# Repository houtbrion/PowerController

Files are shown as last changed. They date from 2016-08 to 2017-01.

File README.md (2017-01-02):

# PowerController
常時運転するRaspberry Piの動作と周囲の環境をArduinoで監視し，
ArduinoでRaspberry Piに供給する電源を制御するシステム．

Raspberry Piが不調に陥った場合に，遠隔からRaspberry Piの電源を強制的にON/OFF
するためにArduinoを遠隔から制御するためのI/Fも提供する．

# 1. システム構成
システムは電源を制御される側のRaspberry Piと，Raspberry Pi用の電源を
制御するArduino，電源制御用端末であるArduinoに遠隔から手動でコマンドを
投入するための遠隔ログイン端末の3種類で構成される．

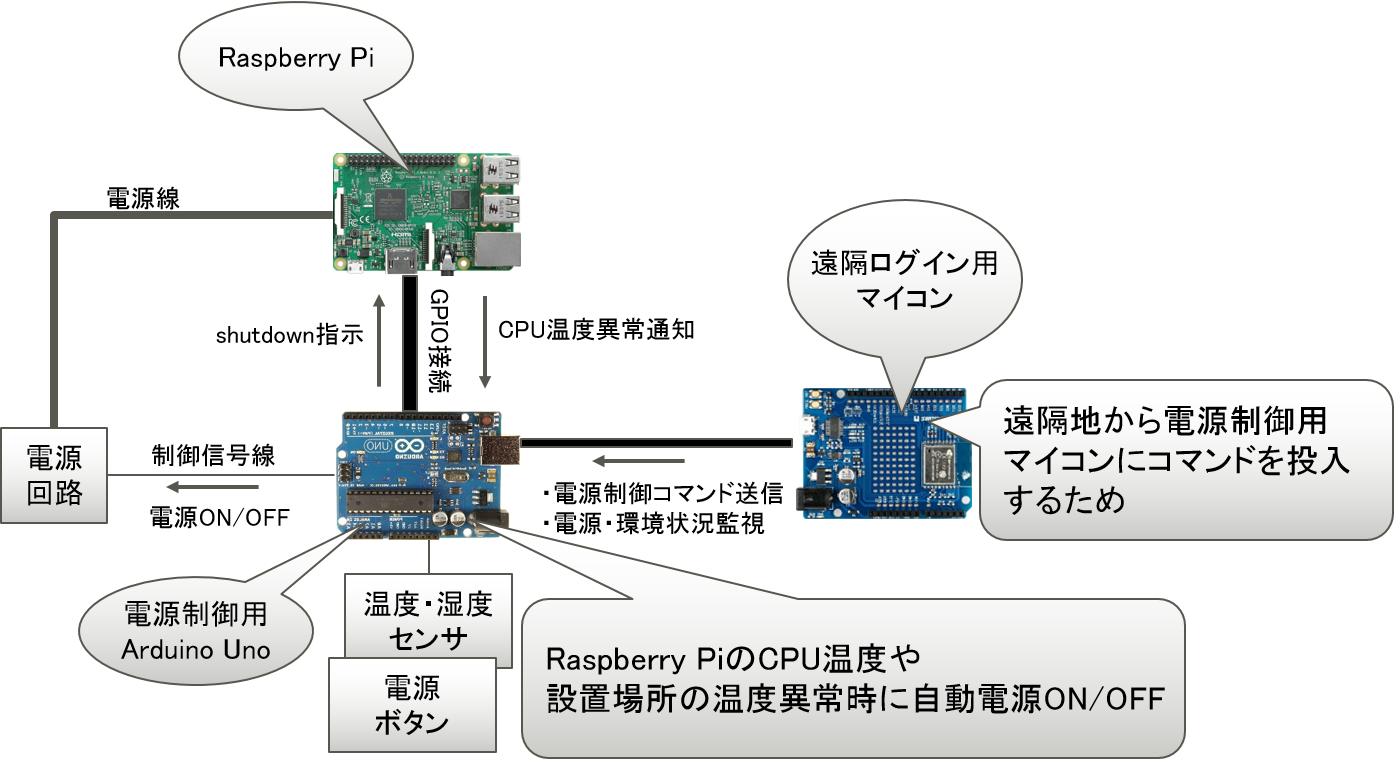
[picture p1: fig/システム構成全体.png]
システム構成図


## 1.1 Raspberry PiとArduinoの連携
電源を制御される側のRaspberry PiのGPIOと電源を制御する側のArduinoのデジタル端子を
接続し，信号をやり取りすることで，人によるRaspberry Piの運用環境の監視やRaspbery Piの
動作の監視を自動化する．

* 強制shutdown信号
Raspberry PiのGPIO端子でArduinoの特定の端子の電圧をdaemonで監視し，Arduinoのある端子の
電圧がHIGHになった場合に，なにかの異常と判定し，shutdownを行う．

* keep alive信号
Raspberry PiのGPIOの特定のピンを定期的にHIにすることで，ArduinoにRaspberry Piが
生きていることを通知する．Arduino(Yun以外の機種の場合)では，Raspberry Piの
keep alive信号端子に接続されているデジタル端子を監視し，一定時間以内に
LOWからHIGHに変化した場合は，Raspberry Piが生きていると判断する．

また，一定時間以上Raspberry Piがkeep alive信号を出さない場合，
ArduinoはRaspberry Piが異常を起こしたと判定し，強制shutdown
信号を出し，一定時間待った後で，Raspbery Piの電源をOFFし，
数秒後に電源をONにする．

この機能を実現するために，割り込み端子が必要であるが，Yunでは端子不足
のため，何度か該当端子を監視し，端子がHIGHである回数で判定する．その
ため，Raspberry Piがkeep alive信号端子をHIGHにした状態でシステムが
フリーズしているとYunは誤判定してしまう．

* CPU高温信号
Raspberry PiのカーネルのCPU温度測定機能を用いて，CPUの温度を常駐
するdaemonで取得し，ある温度以上であった場合は，緊急shutdownが
必要と見なして，Arduinoに通知した後，自らshutdownを行う．

Arduinoは，この信号を受信すると，自らもRaspbery Piに
強制shutdown信号を出して，一定時間後に電源をOFFにした
上で，一定の時間(Arduinoのプログラムで定義しているが数分～数十分間)
電源OFF状態を維持して冷却を待つ．
その後，Raspberry Piの電源をONにする．

## 1.2 Arduinoによる環境監視
電源制御端末であるArduinoでは，上に述べたRaspberry Piの状態監視の他に，これらのシステムが置いてある環境(温度・湿度)の
監視を行っている．

環境の温度が高い状態でシステムの動作を続けていると，高温となるRaspberry PiのCPUや無線回路が破損する可能性が
あるため，環境の温度が高い場合は，Raspberry Piの強制shutdownと電源OFFを行う．その上で，環境の温度が下がる
のを待ち，温度低下後にRaspberry Piの電源をONにする．

## 1.3 遠隔ログイン関連
Raspberry Piに異常が発生し，ハードリセットが必要な場合や，Raspberry PiのCPUが発熱した場合，設置場所が非常に高温になった場合など，
Raspberry Piへの電源供給を強制的に止めるなどの必要があり，そのため，外部からネットワーク経由で電源制御端末である
Arduinoにコマンドを入力する
ための端末．

sshは暗号化処理にメモリとCPUパワーが必要なため，Arduino等のマイコンでは困難．もし，ssh接続が必須となる場合は，
ssh用にRaspberry Piを利用するか，Linuxで動作するモジュールが搭載された機種(Arduino YunやIntel Edison for Arduino)を
利用する必要がある．sshの代わりに，telnetを用いる場合，MCU内蔵のWiFiモジュールが利用可能となるため，
今回の試作では，ESP-WROOM2を搭載した端末(スイッチサイエンスのESPr One)を利用した．
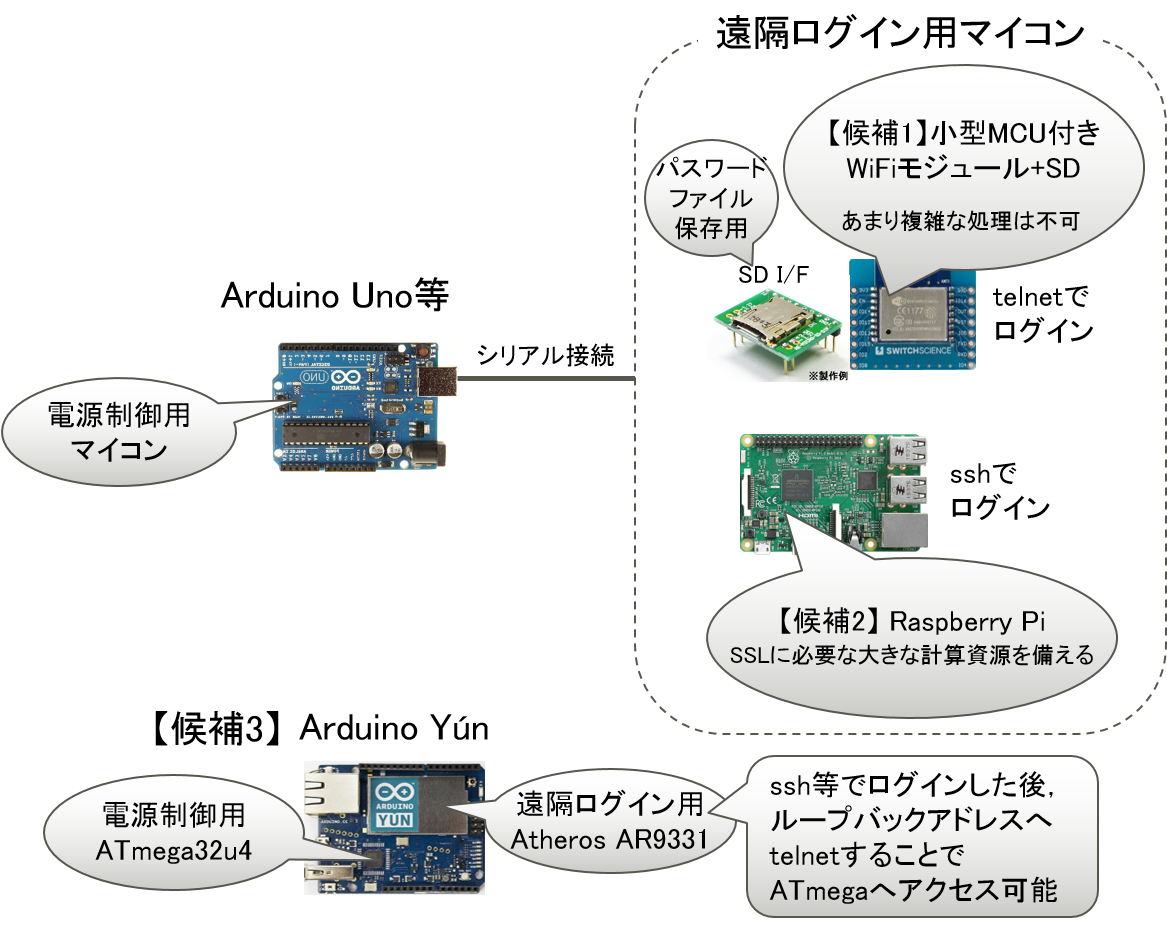
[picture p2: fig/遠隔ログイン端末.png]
遠隔ログイン


### Yunを用いる場合
Arduino Yunを用いる場合は，電源制御端末と遠隔ログイン用端末が1つの筐体に収まるため，
構成が非常に単純になる．Intel Edison for Arduinoの場合も似た構成になるはずであるが，
試していない．
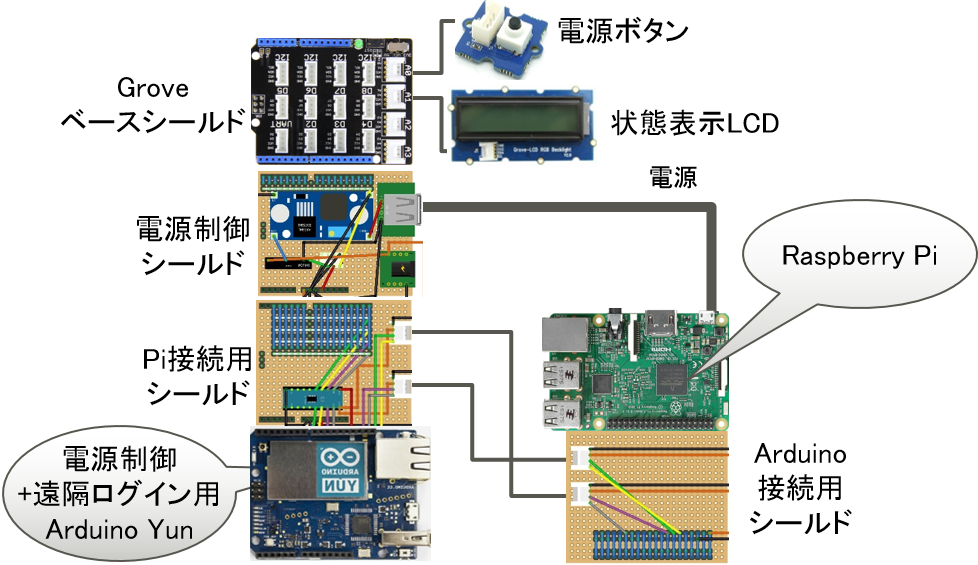
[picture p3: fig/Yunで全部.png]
Yunで兼任


手元のハードで簡単なテストをしたところ，以下の2つの問題に遭遇した．
解決するためには，いろいろハード，ソフト両面で工夫が必要な模様．

- UnoやMegaの場合と，Yunでは動作が異なり，Raspberry Piとの接続線に
ロジックレベル変換回路を用いた場合，Yunの端子(データ読み取り専用)が常に電圧HIGHとなる
ため，動作がうまくいかない．また，Raspberry PiからArduinoに信号を送るために
2つの端子を用い，UnoやMegaでは割り込み処理で対応している．
しかし，Yunでは利用可能な割り込み信号端子5個のうち，4つが
コンソールのシリアルとI2Cの端子と被っているため，
割り込み以外で実装する必要がある．

- MegaやUnoで利用しているRaspberry Pi用電源回路をArduinoのシールド基板に載せたもの
とRaspberry Piと相互接続するためのインターフェース回路(シールド)の2つを同時に
Yun本体に載せると，Yunがまともにブートしない．どちらか，片方のシールドのみだと
動作する． これは，USB経由で給電している電力では，すべてのシールドを駆動する
ために必要な電力を供給できないことが理由．VIN端子にUSBより大きな電力を
供給することが必要．

### ESP-WROOM2を用いる場合
現在のところ，スイッチサイエンスのESPr Oneでテストしているが，
以下の様な問題が発生している．

- ブート時にUSB接続のコンソールをTeraTerm等のコンソールアプリでオープンしないと，ファームが動作しない．
  これは，USB端子を利用せず，ACアダプタで電源供給することで回避できる．
- Arduino側がソフトウェアシリアルではうまく通信できないため，通常のシリアルポートを利用する必要がある．
  標準のシリアルを用いるか，Unoではなく，Megaのようにシリアルが複数ある端末を利用する．
- ArduinoとESPr Oneの間のシリアル接続をオープンすると，接続直後はゴミデータ(ブートメッセージ)が大量にESPr Oneから
  発生し，解釈できないコマンドが大量にArduinoに入力される．

2番目の問題は，ESP8266側もソフトウェアシリアルに変更し，ソフトウェアシリアル同士の
接続にしても改善せず，ESP8266側をソフトウェアシリアル，Arduino側をハードシリアル
でも接続できない．両方ハードシリアルであることが必要．

3番目の問題は，ESP8266のuart0のTxとRxの代わりに，I2CとかSPIのシリアル変換チップを利用することが考えられるが，
スイッチサイエンスのSC16IS750を搭載したモジュールで試した所，ハードウェアフロー制御の端子を用いず，
RxとTxだけで接続(USBシリアル変換経由でPCに接続)すると，文字化けが激しく利用できない状態であった．
Rx,Tx,GNDだけでArduinoと接続して動作する別種のI/Fが必要．

## 1.4 Raspberry Pi自身のCPU温度制御
Raspberry Piで動作するdaemonでは，CPUの温度を監視して，CPU温度が高すぎる場合に
Arduinoと連携して，shutdownや電源ON/OFF
ファンのON/OFFを行うが，単独でもファンのON/OFFを行い，CPU温度の調整をする．

# 2. ソフト
## 2.1 Raspberry Pi用モジュール「powerMNG」
電源を供給される側のRaspberry Piで動作するdaemonで以下の機能を実装．
- 電源制御端末からのShutdown指示信号を監視し，shutdownを実行
- 自分自身のCPU温度を監視し，ファンを制御する信号をON/OFFした上，CPU温度が高すぎる場合に，電源制御端末に異常を通知した後，shutdownを実行

## 2.2 PowerController
周辺の温度と湿度，電源ボタンを監視し，Raspberry Piに供給する電源をON/OFFするArduino用プログラム．
また，周辺の温度・湿度や電源制御状況をLCDに表示する機能もある．

以下は主な機能．
- 周辺の温度が高くなると，Raspberry PiにShutdown信号を出し，一定時間経過後に電源をOFFし，周辺温度が下がるまでその状態を維持
- Raspberry PiからCPU高温信号が来ると，一定時間経過後に電源をOFFし，一定時間経過後に周辺温度が規定値以下なら電源をON
- Raspberry Pi動作中に電源ボタンが押されると，Raspberry PiにShutdown信号を出し，一定時間経過後に電源をOFFし，その状態(強制電源OFF状態)を維持
- 強制電源OFF状態で電源ボタンが押されると，周辺温度を検査し，問題なければRaspberry Piへの電源供給を開始

## 2.3 WiFiTelnetToSerial
遠隔ログイン用にESP-WROOOM2を用いる場合のWROOM2用プログラムで，telnetで接続した場合に，認証を行い，
コマンド入力待ちとなる．コマンド入力待ち状態で接続コマンドが入力されると，電源制御端末のシリアルと中継を行う．
ログアウトする場合は，Linuxのminicomと同じくCtrl-Aでエスケープした後，ログアウトコマンドを入力する．

# 3. ハード

以下の回路(各種マイコン用シールド)は基本的に，電源制御端末は5V動作のもの，それ以外は3.3V駆動を
想定しているが，一部のハードモジュールは5V,3.3Vのどちらでも大丈夫なように設計している．
電源制御回路以外はどちらでも大丈夫なはずであるが，テストしていないため，注意していただきたい．

電源制御端末にArduino Zero等の3.3V動作の端末を用いる場合は，電源制御回路の信号用リレーを3.3V動作の
ものと交換することで対応できるはずである．

以下，幾つかの相互接続用のPiとArduino用のシールド基板の図面を示すが，図面そのものは『ハード関係』ディレクトリに収容している．また，Mega用のシールド基板の図面などもあるため，『ハード関係』ディレクトリを良く見ていただきたい．

## 3.1 Raspberry Pi関係

## 3.1 電源制御シールドUNO用
### ユニバーサル基板図面
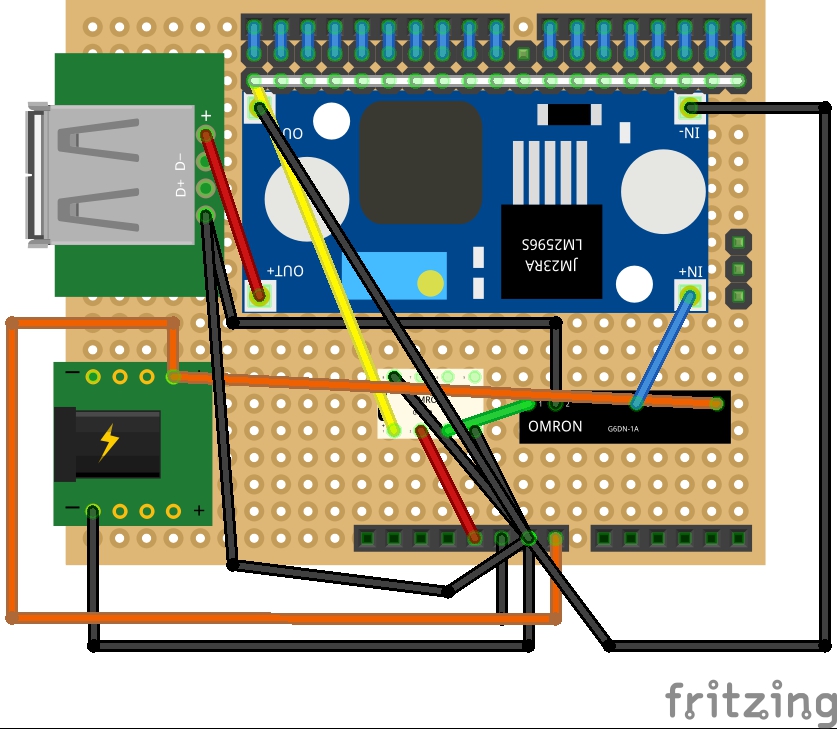
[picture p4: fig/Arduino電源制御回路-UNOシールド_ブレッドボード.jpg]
Arduino電源制御回路-UNOシールド_ブレッドボード


### 回路図
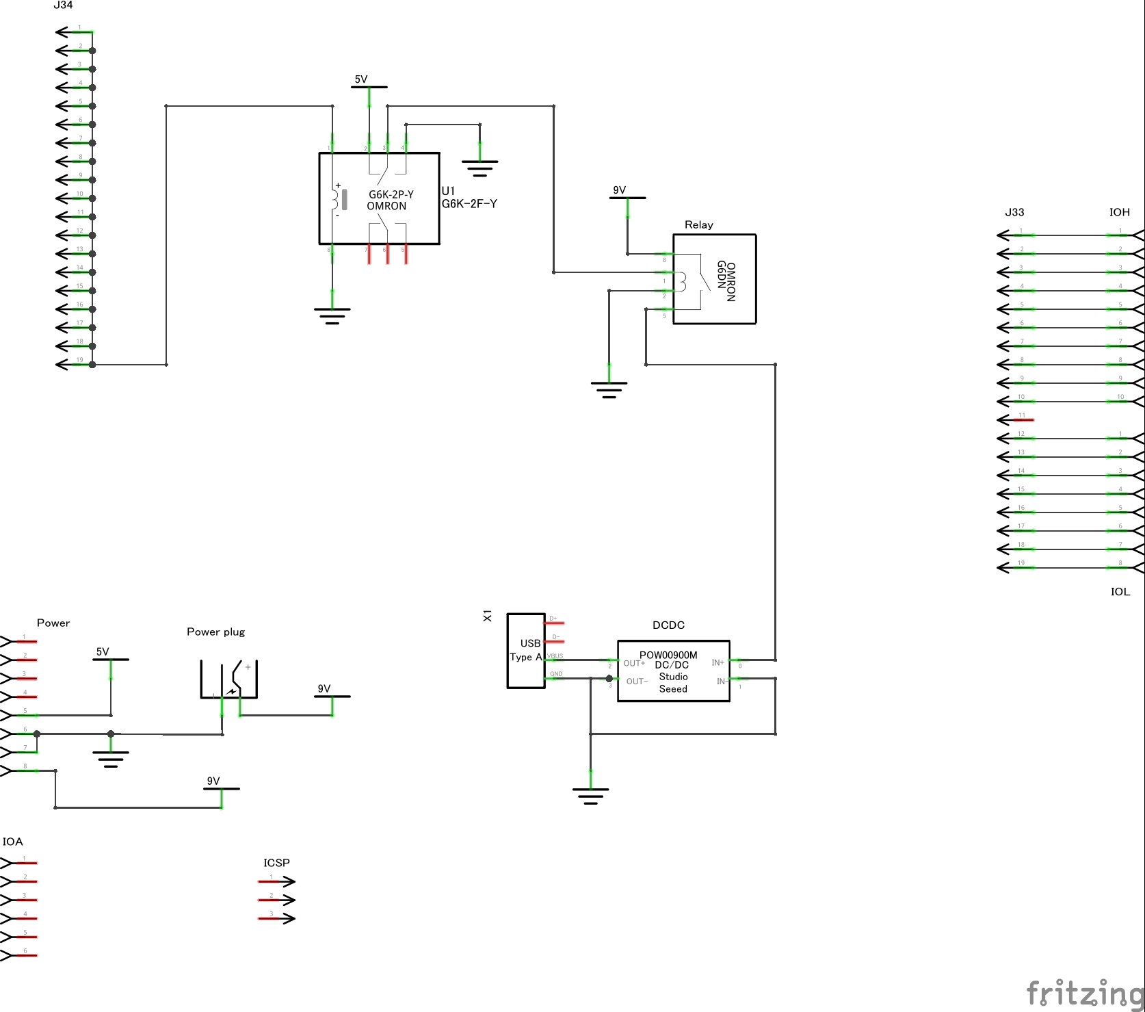
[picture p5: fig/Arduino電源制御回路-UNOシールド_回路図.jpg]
Arduino電源制御回路-UNOシールド_回路図


## 3.2 電源制御シールドYun用
### ユニバーサル基板図面
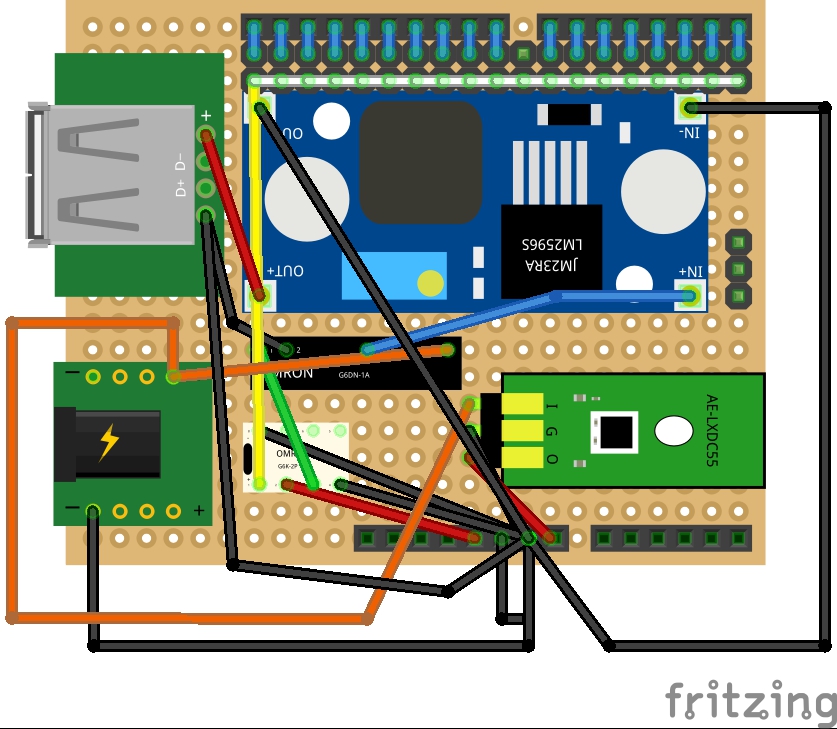
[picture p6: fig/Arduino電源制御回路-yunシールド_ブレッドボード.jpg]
Arduino電源制御回路-yunシールド_ブレッドボード

### 回路図
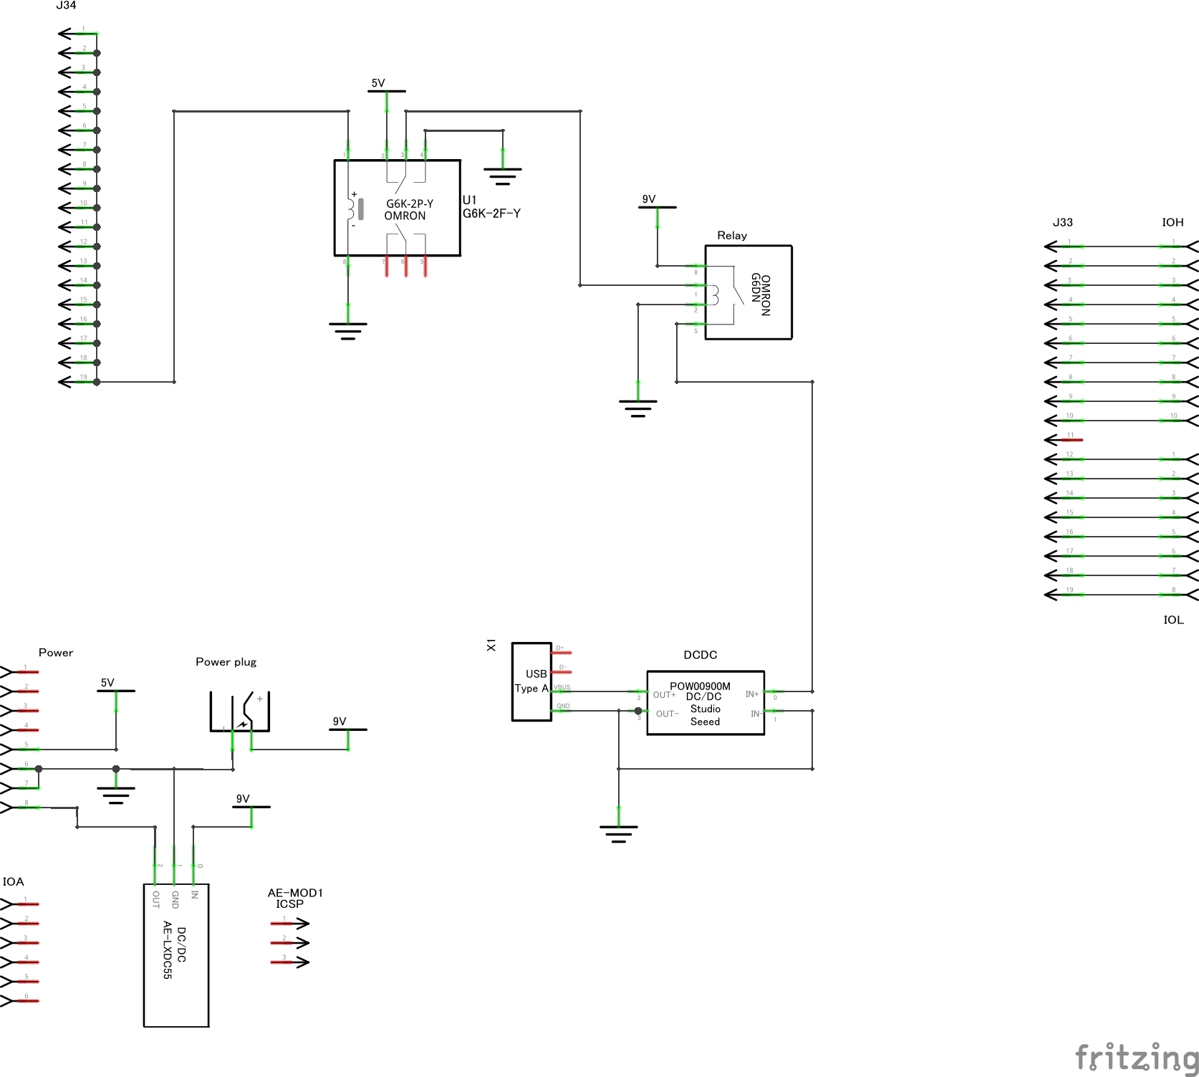
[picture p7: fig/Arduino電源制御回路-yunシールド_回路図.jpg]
Arduino電源制御回路-yunシールド_回路図


## 3.3 Pi-Arduino相互接続シールド Arduino用
### ユニバーサル基板図面
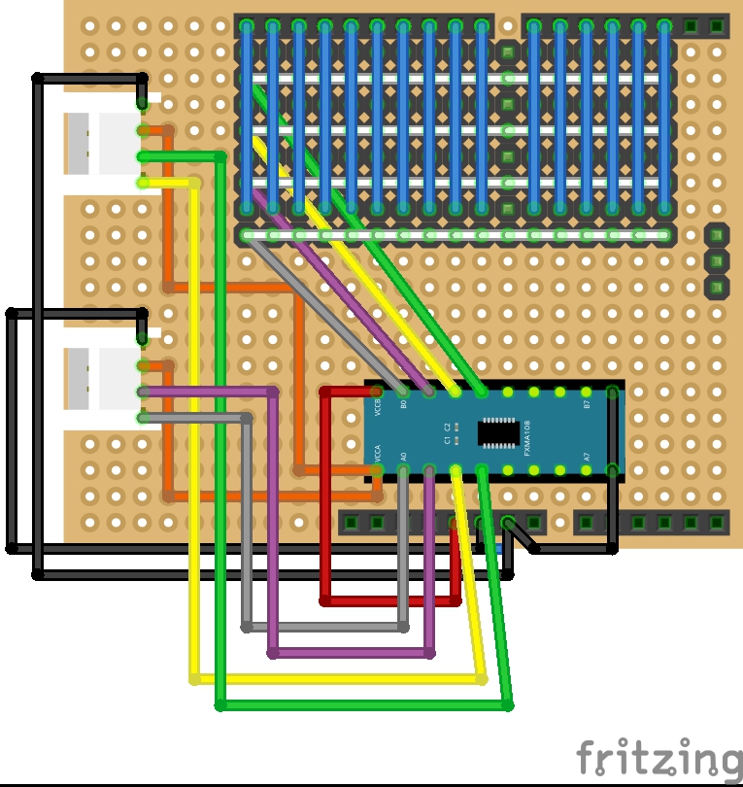
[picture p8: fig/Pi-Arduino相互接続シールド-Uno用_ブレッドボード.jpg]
Pi-Arduino相互接続シールド-Uno用_ブレッドボード

### 回路図
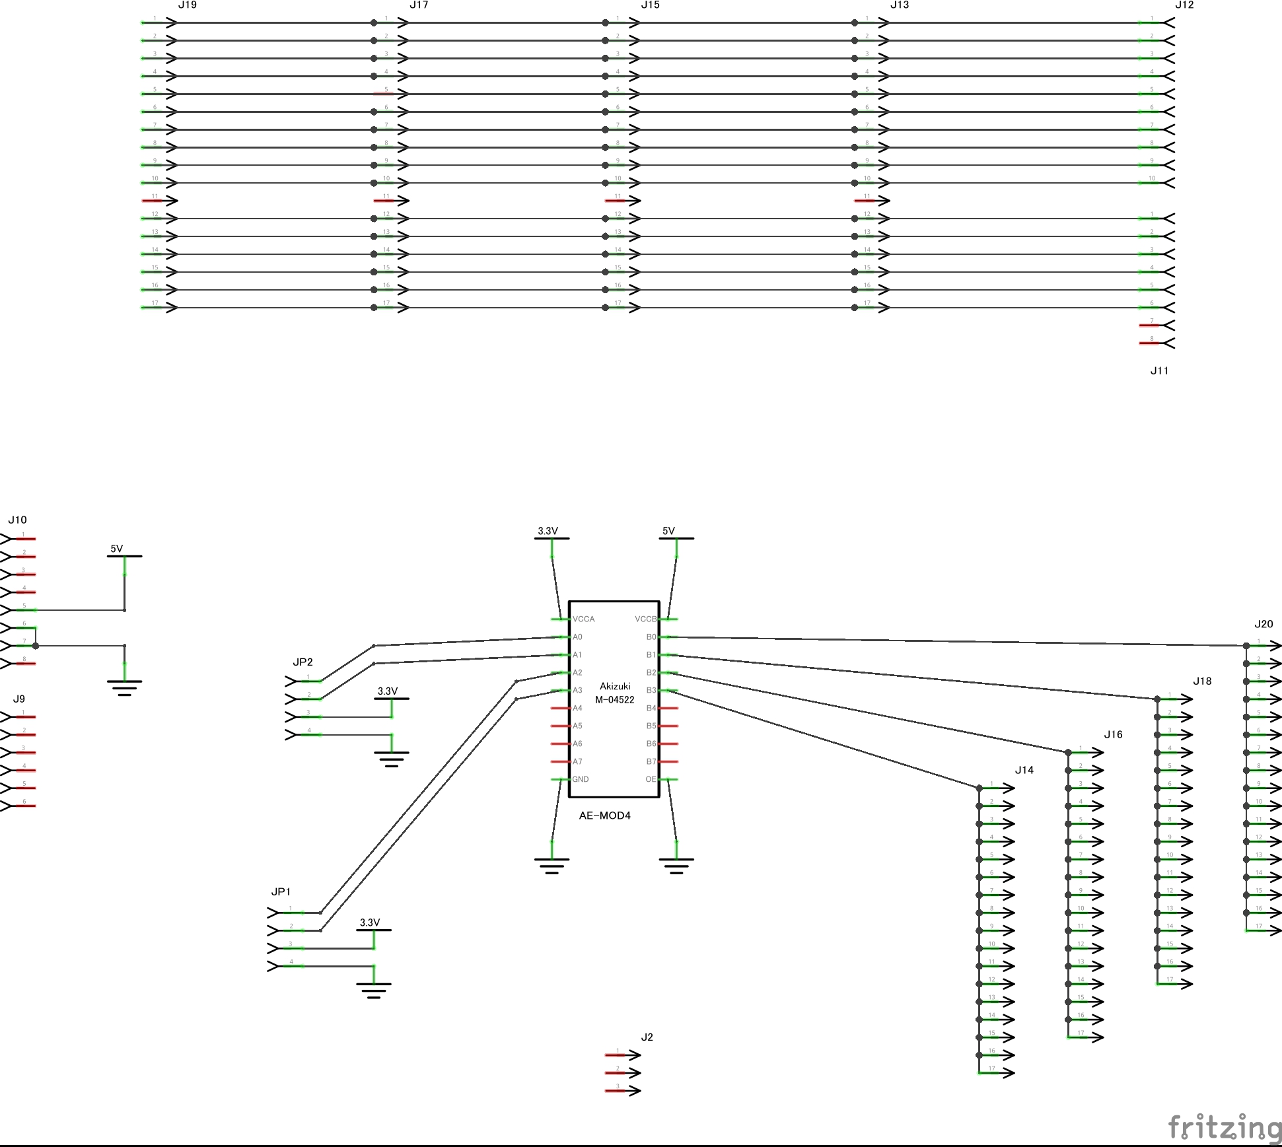
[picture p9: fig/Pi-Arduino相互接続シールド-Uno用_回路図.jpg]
Pi-Arduino相互接続シールド-Uno用_回路図


## 3.4 Pi-Arduino相互接続シールド Pi用
### ユニバーサル基板図面
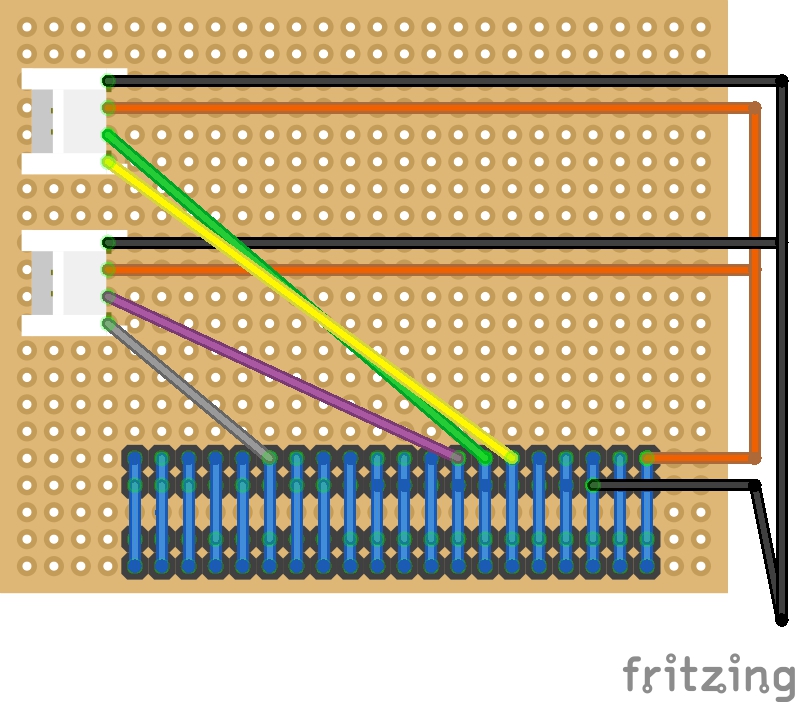
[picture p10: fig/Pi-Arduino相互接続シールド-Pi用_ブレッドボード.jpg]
Pi-Arduino相互接続シールド-Pi用_ブレッドボード

### 回路図
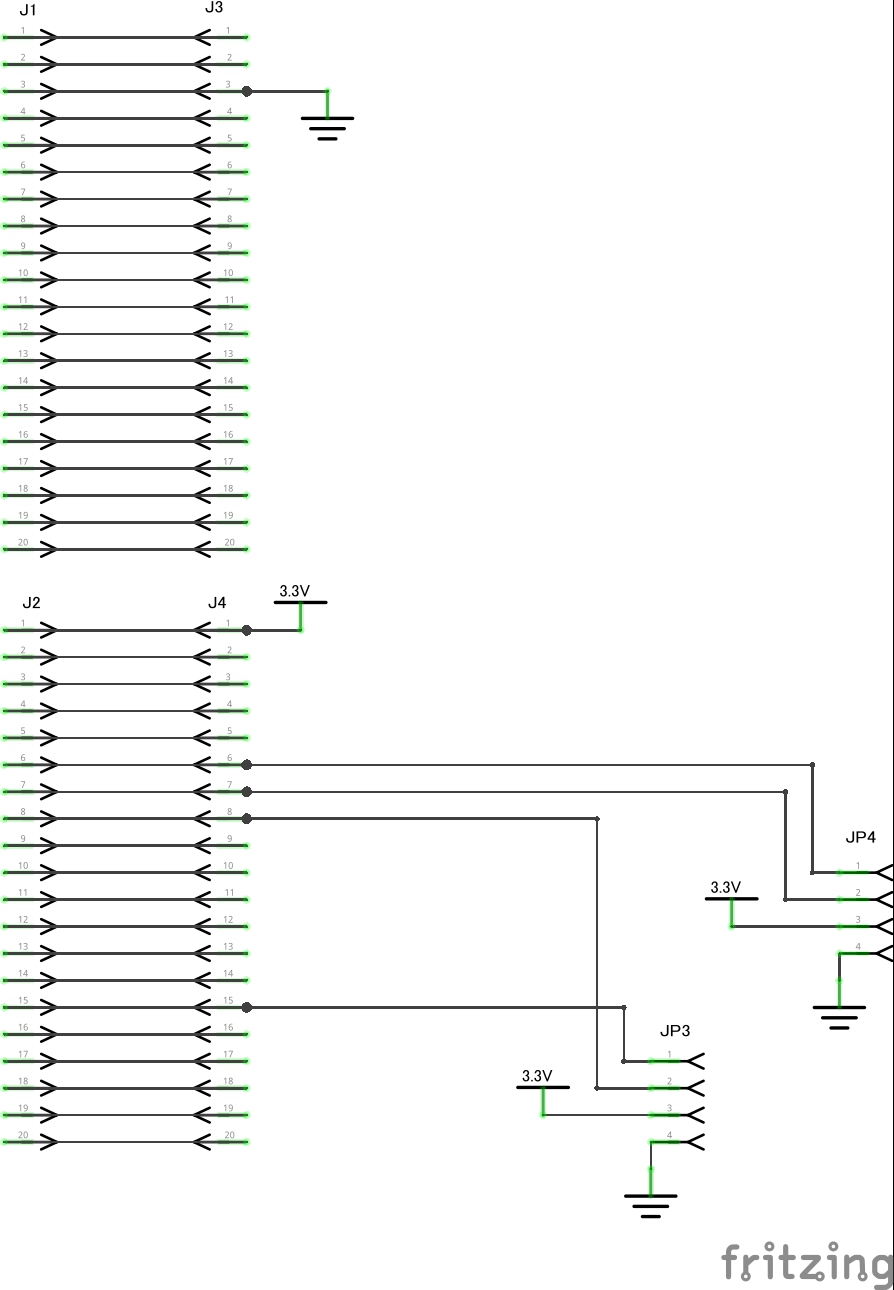
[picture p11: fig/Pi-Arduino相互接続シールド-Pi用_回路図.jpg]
Pi-Arduino相互接続シールド-Pi用_回路図


## 3.5 WROOM2-Arduino相互接続シールド Arduino用
### ユニバーサル基板図面
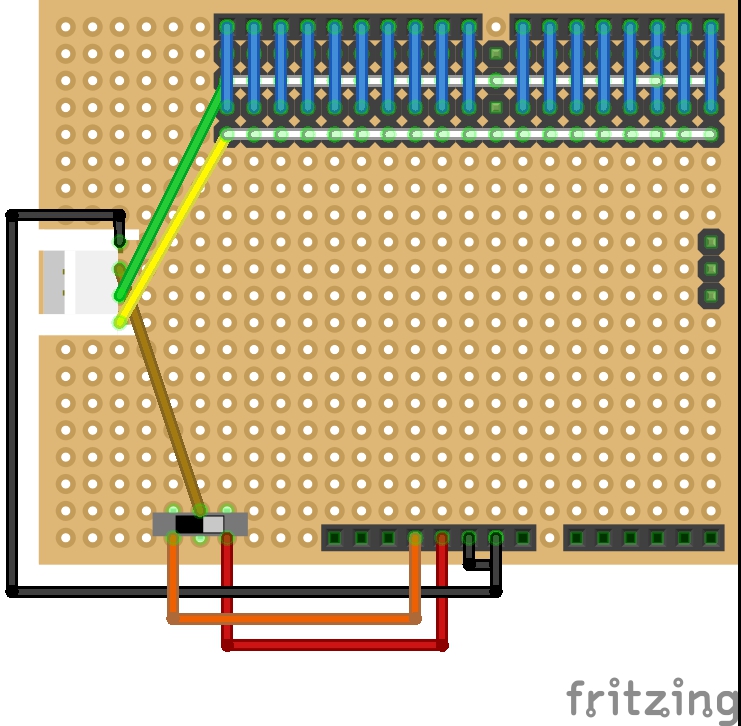
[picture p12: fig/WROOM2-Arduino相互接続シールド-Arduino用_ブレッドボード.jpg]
WROOM2-Arduino相互接続シールド-Arduino用_ブレッドボード

### 回路図
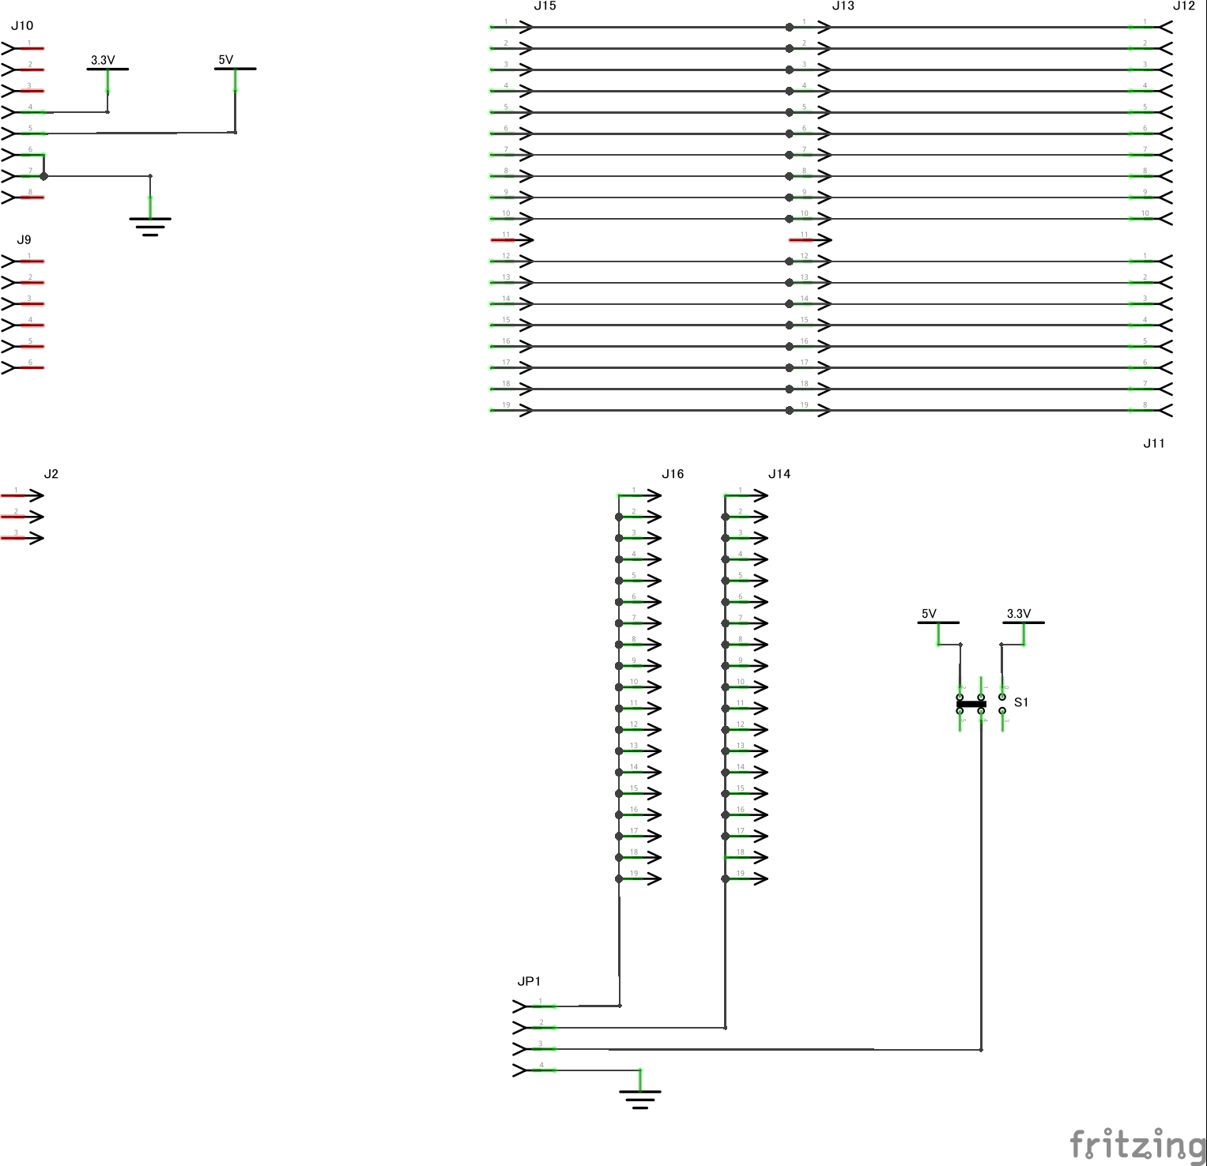
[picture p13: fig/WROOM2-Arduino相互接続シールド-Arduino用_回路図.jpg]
WROOM2-Arduino相互接続シールド-Arduino用_回路図


## 3.6 WROOM2-Arduino相互接続シールド WROOM2用
### ユニバーサル基板図面
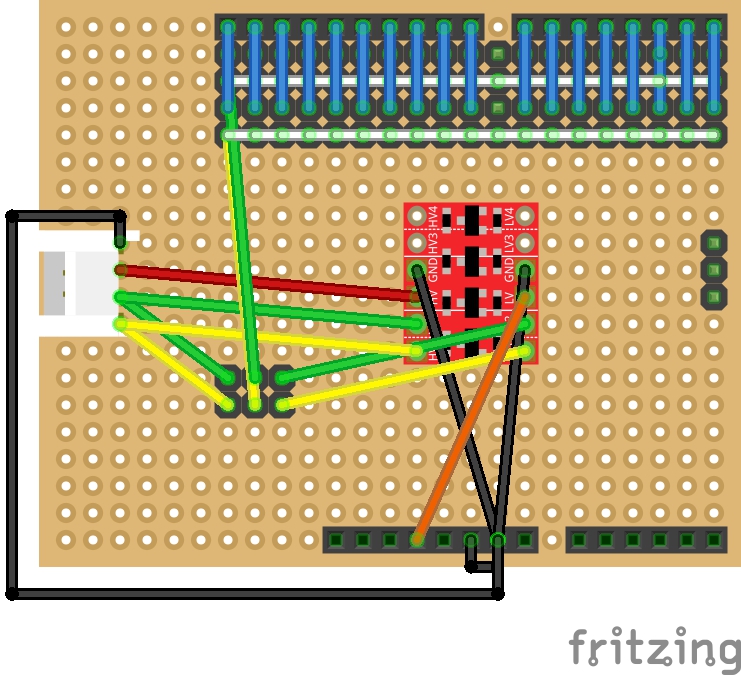
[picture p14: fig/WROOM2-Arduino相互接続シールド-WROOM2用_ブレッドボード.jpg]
WROOM2-Arduino相互接続シールド-WROOM2用_ブレッドボード

### 回路図
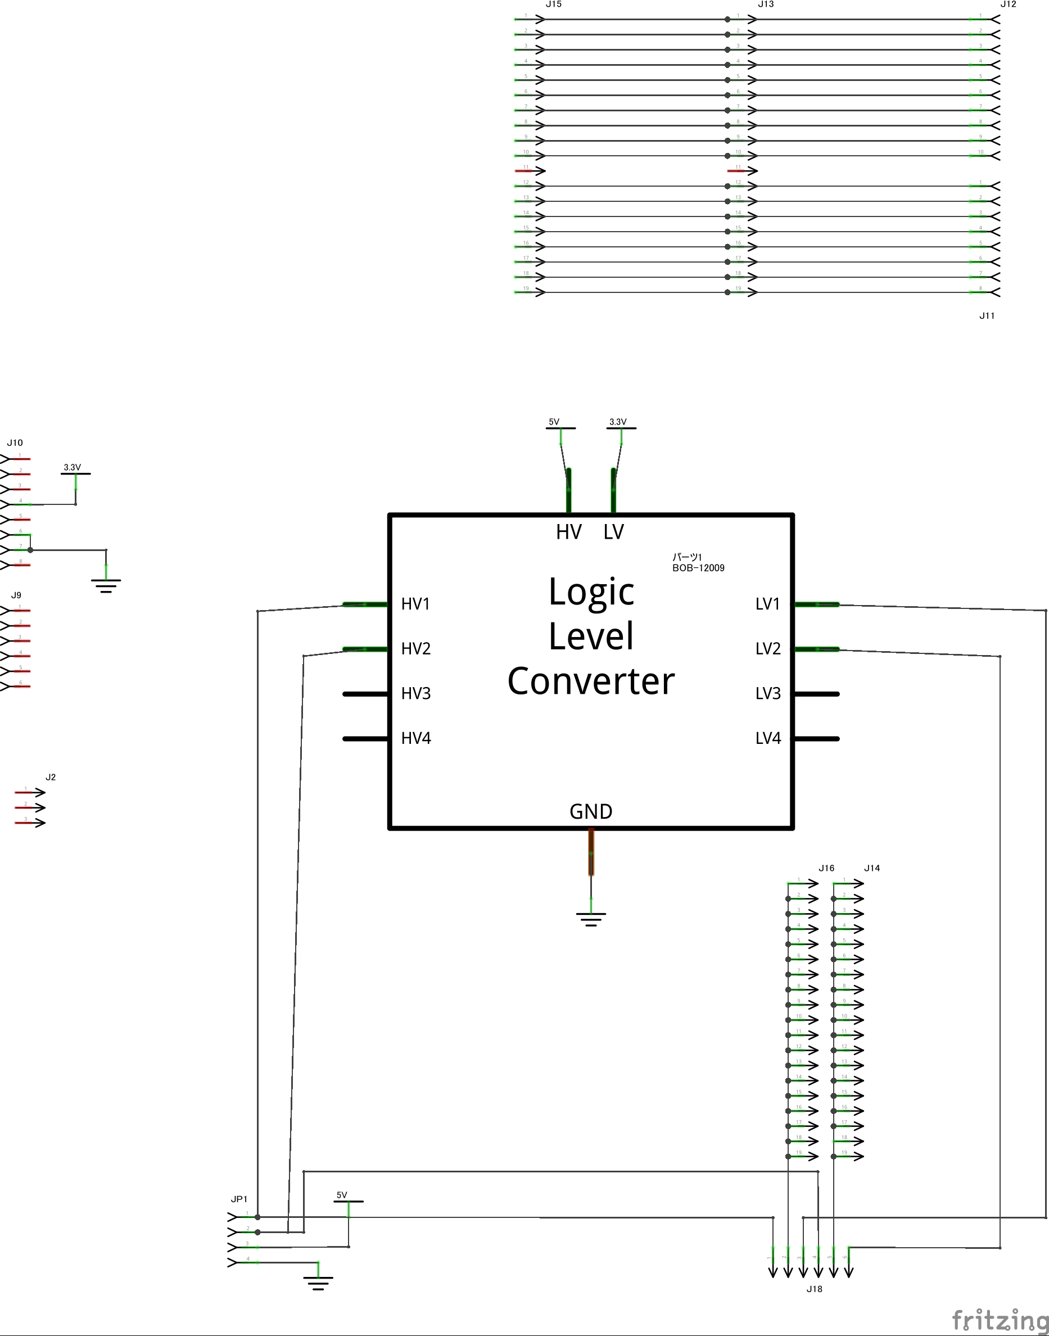
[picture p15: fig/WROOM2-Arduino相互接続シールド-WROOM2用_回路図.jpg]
WROOM2-Arduino相互接続シールド-WROOM2用_回路図


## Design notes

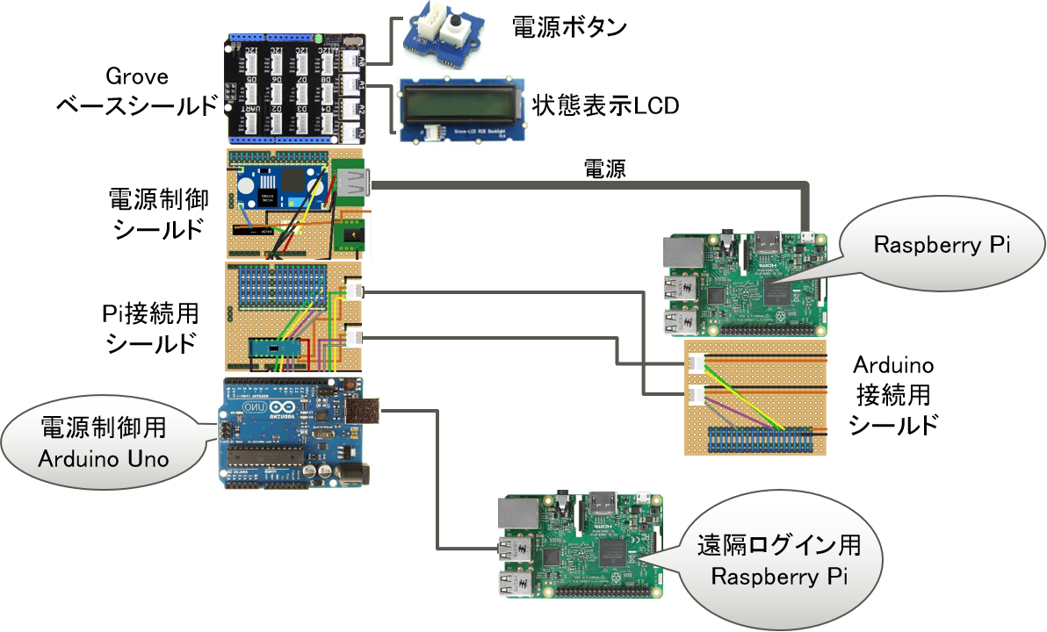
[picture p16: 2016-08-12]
fig/RaspberryPiでログイン.png

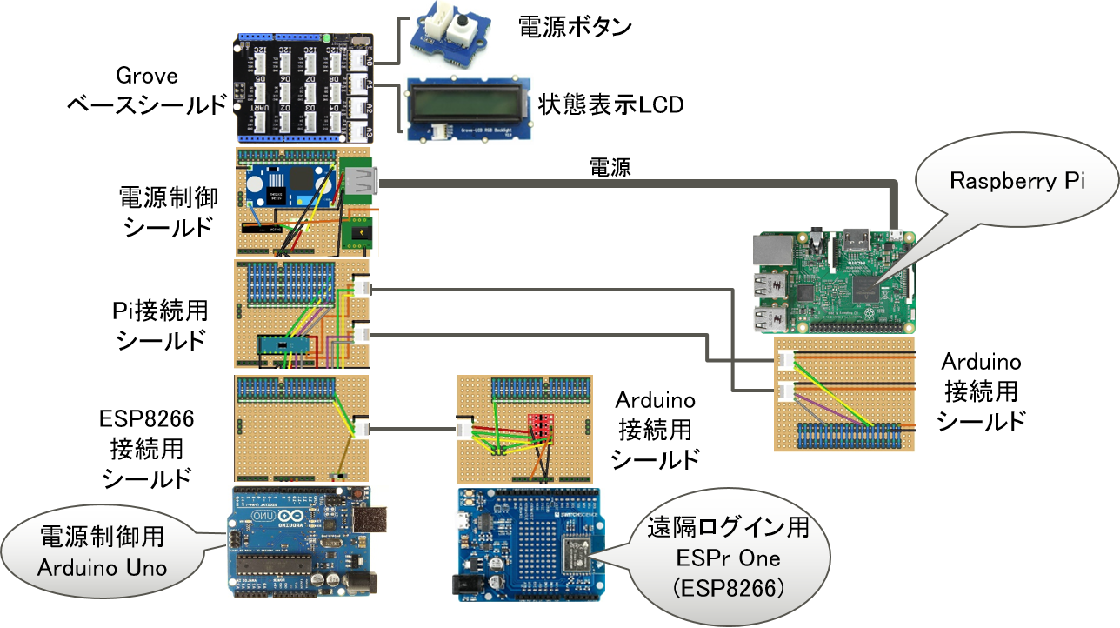
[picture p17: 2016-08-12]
fig/ESPr-Oneでログイン.png

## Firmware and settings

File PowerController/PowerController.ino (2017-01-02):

/**************** カスタマイズする可能性がある定数定義 ****************/

#include "PowerControllerConfig.h"

/**************** カスタマイズ不要な定数定義 ****************/
/*
  状態定義
    種類                   状態名
    通常                 STATE_NORMAL
    電源OFF              STATE_OFF
    強制電源OFF          STATE_FOFF
    通常管理             STATE_NORMAL_CONTROL
    強制電源OFF管理      STATE_FOFF_CONTROL
    電源OFF管理          STATE_OFF_CONTROL
 */
#define STATE_NORMAL         0
#define STATE_OFF            1
#define STATE_FOFF           2
#define STATE_NORMAL_CONTROL 3
#define STATE_FOFF_CONTROL   4
#define STATE_OFF_CONTROL    5

/*
  管理用インターフェースの定義
    channdelID   physical link
       0             Serial
       1             network

*/
#define CONSOLE_SERIAL     0
#define CONSOLE_NETWORK    1

/*
   管理者用コマンド
     COMMAND_CONTROL_MODE  'L' : 管理者モードに移行(ログイン)
     COMMAND_SHUTDOWN      'S' :shutdown         (shutdownピンを1秒HIGH)
     COMMAND_POWER_ON      'U' :Power ON         (リレー用端子をLOW)
     COMMAND_POWER_DOWN    'D' :Power OFF        (リレー用端子をHIGH)
     COMMAND_INFO          'I' :Info            (各種の状態を返す)
         リレー端子の状態
         温度警告があったか否か
         (オプション) 周囲の温度
         直前の状態
         管理者モードから抜けた場合の行き先(状態)
    COMMAND_HELP          'H'|'?' : HELP             (コマンドの説明の出力)
    COMMAND_EXIT          'Q' : Quit  管理者モードを抜ける
    COMMAND_UNKNOWN       コマンドに対応しない文字の入力時
    COMMAND_NONE          入力なし
*/
#define COMMAND_NONE          0
#define COMMAND_CONTROL_MODE  1
#define COMMAND_SHUTDOWN      2
#define COMMAND_POWER_ON      3
#define COMMAND_POWER_DOWN    4
#define COMMAND_INFO          5
#define COMMAND_HELP          6
#define COMMAND_EXIT          7
#define COMMAND_UNKNOWN       8

/*
   環境温度の監視結果を示す定数
 */
#define ENV_TEMPERATURE_ERROR -1
#define ENV_TEMPERATURE_LOW    0
#define ENV_TEMPERATURE_MID    1
#define ENV_TEMPERATURE_HIGH   2

/**************** プログラム ****************/
/*
   ヘッダファイルのインクルード
 */
#include "DHT.h"
#include "Time.h"
#include "PowerController.h"
#ifdef LCD
#include <Wire.h>
#include "rgb_lcd.h"
#endif /* LCD */

#ifdef SOFT_SERIAL
#include <SoftwareSerial.h>
#define CONSOLE sSerial
#endif /* SOFT_SERIAL */

#ifdef SERIAL
#define CONSOLE Serial
#endif /* SERIAL */

#ifdef SERIAL1
#define CONSOLE Serial1
#endif /* SERIAL1 */

#ifdef SERIAL2
#define CONSOLE Serial2
#endif /* SERIAL2 */

#ifdef SERIAL3
#define CONSOLE Serial3
#endif /* SERIAL3 */

#ifdef BRIDGE
#include <Console.h>
#define CONSOLE Console
#endif /* BRIDGE */

#ifdef SOFT_WDT
#include <avr/wdt.h>
#endif /* SOFT_WDT */
/*
    各種変数型の定義とグローバル変数の定義&初期化
 */
 
eventType event;                               //イベントを格納する変数の定義と初期化
time_t timer;                                  // CPU高温時の冷却時間のタイマ
time_t commandLineTimer;                       // 管理者コンソールの自動ログオフのタイマ
volatile time_t keepAlive;                     // keep alive信号のタイマ変数

int currentState=-1;                           // システム(状態遷移機械)の状態を格納する変数
volatile boolean highTemperature=false;        // 過去に高温信号が上がったか否か
#ifndef NO_INTERRUPT
volatile boolean highTemperatureEvent=false;   // 高温信号の有無の一時格納用 (イベント監視の関数は常時初期化されるため)
volatile boolean keepAliveFlag=false;
#endif /* NO_INTERRUPT */

time_t infoTimer;

DHT dht;

#ifdef SOFT_SERIAL
SoftwareSerial sSerial(SOFT_SERIAL_RX, SOFT_SERIAL_TX); // RX, TX
#endif


#ifdef LCD
rgb_lcd lcd;
#endif /* LCD */
#ifdef LCD
void lcd_normal(){
  lcd.setRGB(255,255,255); // 白
}
void lcd_info(){
  lcd.setRGB(10,10,200); //  青
}
void lcd_causion(){
  lcd.setRGB(150,150,0); // 黄色
}
void lcd_allert(){
  lcd.setRGB(255,0,100); // 赤
}
#endif /* LCD */


#ifdef DEBUG
void dumpEvent(){
  Serial.print(F("keep alive = "));
  Serial.print((event.keepAlive ? "true" : "false"));
  Serial.print(F(" , highTemperature = "));
  Serial.print((event.highTemperature ? "true" : "false"));
  Serial.print(F(" , timerFire = "));
  Serial.print((event.timerFire ? "true" : "false"));
  Serial.print(F(" , commandLineTimeOut = "));
  Serial.println((event.commandLineTimeOut ? "true" : "false"));
  Serial.print(F("envTemperature = "));
  Serial.print(event.envTemperature);
  Serial.print(F(" , commandInput = "));
  Serial.print(event.commandInput);
  Serial.print(F(" , commandInputChar="));
  Serial.println(event.commandInputChar);
  Serial.print(F("current state = "));
  switch (currentState) {
    case STATE_NORMAL:
      Serial.println(F("STATE_NORMAL"));
      break;
    case STATE_OFF:
      Serial.println(F("STATE_OFF"));
      break;
    case STATE_FOFF:
      Serial.println(F("STATE_FOFF"));
      break;
    case STATE_NORMAL_CONTROL:
      Serial.println(F("STATE_NORMAL_CONTROL"));
      break;
    case STATE_FOFF_CONTROL:
      Serial.println(F("STATE_FOFF_CONTROL"));
      break;
    case STATE_OFF_CONTROL:
      Serial.println(F("STATE_OFF_CONTROL"));
  }
#ifdef DHT_WAIT
  delay(dht.getMinimumSamplingPeriod());
#endif /* DHT_WAIT */

  // Reading temperature or humidity takes about 250 milliseconds!
  // Sensor readings may also be up to 2 seconds 'old' (its a very slow sensor)
  float h = dht.getHumidity();
  // Read temperature as Celsius (the default)
  float t = dht.getTemperature();

  Serial.print(F("Humidity: "));
  Serial.print(h);
  Serial.print(F(" %\t"));
  Serial.print(F("Temperature: "));
  Serial.print(t);
  Serial.print(F(" *C "));
  Serial.print(F("now = "));
  Serial.print(now());
  Serial.print(F(" , timer="));
  Serial.print(timer);
  Serial.print(F(" , commandLineTimer = "));
  Serial.print(commandLineTimer);
  Serial.print(F(" , keepAlive = "));
  Serial.println(keepAlive);
}
#endif /* DEBUG */


#ifndef NO_INTERRUPT
/*
 * 割り込み処理の定義
 */
void keepAliveINT(){          // keep alive信号の割り込み処理
  keepAliveFlag=true;
}

void highTemperatureINT() {   // CPU高温信号が割り込み処理
  highTemperature=true;       // CPU高温警告が過去に上がったか否か(冷却処理とコマンドラインでのINFOコマンドのため) 冷却時間が過ぎるまで消さない
  highTemperatureEvent=true;  // CPU高温警告が上がったか否かの一時格納
}
#endif /* NO_INTERRUPT */

/*
 * 管理用インターフェースの文字入出力の仮想化
 */
/*
void printMessage(char *buff, int channelID) {  // 管理者用インターフェースをネットワークに対応させるための準備(ネットワークは未対応)
  switch(channelID) {
    case CONSOLE_SERIAL :
      Serial.print(buff);
      break;
    case CONSOLE_NETWORK :
      break;
  }
}
*/
/*
 * システムログの出力
 */
/*
void printLog(char *buff){  // 将来ログをファイルに保存する可能性があるための準備(未対応)
  Serial.print(buff);
}
*/
/*
 * 各種タイマのスタート処理
 */
void startTimer(){ // 高温時等の電源On/Offの待ち時間用タイマのスタート
  timer=now();
}
void startCommandLineTimer(){ // コマンドラインのオートログオフ用タイマのスタート
  commandLineTimer=now();
}

/*
 * 管理者インターフェースから入力されたコマンド(文字)の解析処理
 */
int commandLex(char input){
  switch (input) {
    case 'L': // シリアルポートで管理者がコマンドモードを利用する場合の合図
    case 'l':
      return COMMAND_CONTROL_MODE;
    case 'S': // Piをシャットダウンするコマンド
    case 's':
      return COMMAND_SHUTDOWN;
    case 'U': // 強制電源ON
    case 'u':
      return COMMAND_POWER_ON;
    case 'D': // 強制電源OFF
    case 'd':
      return COMMAND_POWER_DOWN;
    case 'I': // 現在状態の観測と表示
    case 'i':
      return COMMAND_INFO;
    case 'H': // ヘルプ
    case 'h':
    case '?':
      return COMMAND_HELP;
    case 'Q': // 管理者コマンドモードからのログアウト
    case 'q':
      return COMMAND_EXIT;
  }
  return COMMAND_UNKNOWN; // 未定義の文字が入力された
}

#ifdef LCD
void printStateLCD(float humidity,float temperature,int currentState){
  char buff[20];
  lcd.clear();
  if (isnan(humidity) || isnan(temperature)) {
    lcd.print(F("Sensor error."));
  } else {
    sprintf(buff,"T = %d ,H = %d", int(temperature), int(humidity));
    lcd.print(buff);
  }
  switch(currentState) {
    case STATE_NORMAL:
    case STATE_NORMAL_CONTROL:
      lcd.setCursor(0, 1);
      lcd.print(F("State=NORMAL"));
      break;
    case STATE_OFF:
    case STATE_OFF_CONTROL:
      lcd.setCursor(0, 1);
      lcd.print(F("State=OFF"));
      break;
    case STATE_FOFF:
    case STATE_FOFF_CONTROL:
      lcd.setCursor(0, 1);
      lcd.print(F("State=FOFF"));
  }
}
#endif /* LCD */

/*
 * イベント監視
 */
void checkEvent(){
  if (LOW==digitalRead(POWER_PIN)) {
    event.powerPinCounter=0;
  } else {
    event.powerPinCounter++;
  }
#ifdef DEBUG_POWER_PIN
  Serial.print("powerPinCounter = ");
  Serial.println(event.powerPinCounter);
#endif /* DEBUG_POWER_PIN */
  // Raspberry Piのkeep alive信号が一定時間以内に観測できたか否かの判定
#ifdef NO_INTERRUPT
  if (HIGH==digitalRead(KEEP_ALIVE_PIN)) {
    keepAlive=now();            // keep alive信号が上がった時間の格納
  }
#else /* NO_INTERRUPT */
  if (keepAliveFlag==true) {
    keepAlive=now();            // keep alive信号が上がった時間の格納
    keepAliveFlag=false;
  }
#endif /* NO_INTERRUPT */
  if ((keepAlive+KEEP_ALIVE_THRESHOLD) < now()) { // 前回の観測時間に制限時間を加えたものが現在時刻より未来になっていない場合は，タイムアウト (エラー発生)
    event.keepAlive=true;
  } else {                                        // タイムアウトになっていない(制限時間内)の場合
    event.keepAlive=false;
  }
#ifdef NO_INTERRUPT
  if (HIGH==digitalRead(HIGH_TEMP_PIN)) {
    event.highTemperature=true;
  }
#else /* NO_INTERRUPT */
  event.highTemperature=highTemperatureEvent;     // 割り込みで立てられたフラグの値を書き写す
  highTemperatureEvent=false;                     // 割り込みで立てられたフラグの値を消す
#endif /* NO_INTERRUPT */

#ifdef DHT_WAIT
  delay(dht.getMinimumSamplingPeriod());
#endif /* DHT_WAIT */
  float humidity = dht.getHumidity();            // 湿度の読み取り
  float temperature = dht.getTemperature();      // 温度の読み取り
  // 温度と湿度の読み取りに成功したか否かの判定
  if (isnan(humidity) || isnan(temperature)) {
    // どちらかが失敗している
    event.envTemperature=ENV_TEMPERATURE_ERROR;
  } else {
    // 両方の読み取りに成功した場合は，温度を区分け
    if (temperature < HI_LOW_THRESHOLD) {                  // 温度 『低』
      event.envTemperature=ENV_TEMPERATURE_LOW;
    } else if (temperature < HI_HIGH_THRESHOLD) {          // 温度 『中』
      event.envTemperature=ENV_TEMPERATURE_MID;
    } else {                                               // 温度 『高』
      event.envTemperature=ENV_TEMPERATURE_HIGH;
    }
  }
  printStateLCD(humidity,temperature,currentState);
  if (CONSOLE.available() > 0) {                  // シリアルポートへの入力に対する処理
    // シリアルポートに文字入力がある場合
    // 入力された文字がどのコマンドに対応するか解析(lex)し，生文字を保存して返す．
    char incomingByte = 0;
    // read the incoming byte:
    incomingByte = CONSOLE.read();
    if ((incomingByte>31) && (incomingByte<127)){
      startCommandLineTimer();                      // コマンドが何か入力された場合は，タイムアウト処理のためのタイマを走らせる．
      event.commandInput = commandLex(incomingByte);
      event.commandInputChar = incomingByte;
    }
  } else {
    // シリアルポートに文字入力がない場合は，『なし』で返答
    event.commandInput=COMMAND_NONE;
    event.commandInputChar=(char)0;
  }
  if ((timer!=0) && ((timer+HIGH_TEMPERATURE_WAIT_DURATION)<now())) { // CPU高温に対応するための，冷却時間が過ぎたか否かの判定
    event.timerFire=true;
    timer=0;
  } else {
    event.timerFire=false;
  }
  if ((commandLineTimer+COMMAND_LINE_WAIT_DURATION)< now()) { // コマンドラインの自動ログアウトの制限時間を超過しているか否かの判定
    event.commandLineTimeOut=true;
  } else {
    event.commandLineTimeOut=false;
  }
}

/*
     プリントinfo : 管理者コマンドモードで，Infoコマンドを入力された際の処理
       現在の『運転』状態の表示
       Raspberry PiのCPU高温警告が上がったための冷却待ち時間中か否か
       環境の温度・湿度の測定と体感温度の計算
 */
void printInfo(int state) {
  //printMessage("Current status: ",CONSOLE_SERIAL ); // 現在状態表示のヘッダ部分
  CONSOLE.print("Current status: ");
  switch (state) {                                    // 現在状態の表示 (管理者モードは普通の運転状態とマージ)
    case STATE_NORMAL:
    case STATE_NORMAL_CONTROL:
      //printMessage("Normal\n",CONSOLE_SERIAL);
      CONSOLE.println("Normal");
      break;
    case STATE_OFF:
    case STATE_OFF_CONTROL:
      //printMessage("Power off\n",CONSOLE_SERIAL);
      CONSOLE.println("Power off");
      break;
    case STATE_FOFF:
    case STATE_FOFF_CONTROL:
      //printMessage("Force power off\n",CONSOLE_SERIAL);
      CONSOLE.println("Force power off");
      break;
  }
  if (highTemperature) {                               // Raspberry PiからCPU温度警告による対応処理中か否かの表示
    //printMessage("Raspberry Pi CPU temperature alart : YES\n",CONSOLE_SERIAL);
    CONSOLE.println("Raspberry Pi CPU temperature alart : YES");
  } else {
    //printMessage("Raspberry Pi CPU temperature alart : NO\n",CONSOLE_SERIAL);
    CONSOLE.println("Raspberry Pi CPU temperature alart : NO");
  }
  // 環境の温・湿度を測定し，体感温度を計算する
  char buff[128];
#ifdef DHT_WAIT
  delay(dht.getMinimumSamplingPeriod());
#endif /* DHT_WAIT */
  float h = dht.getHumidity();
  float t = dht.getTemperature();
  //sprintf(buff,"Environment temperature = %d , humidity = %d\n",(int)t,(int)h);
  //printMessage(buff,CONSOLE_SERIAL);
  CONSOLE.print("Environment temperature = ");
  CONSOLE.print(int(t));
  CONSOLE.print(" , humidity = ");
  CONSOLE.println(int(h));
}

/*
 * INFO以外の各コマンドの処理と下請け関数
 */
/*
    電源用リレーの制御
      引数flag == true  : Power ON         (リレー用端子をLOW)
      引数flag == false : Power OFF        (リレー用端子をHIGH)
 */

void relayControl(boolean flag){
  if (flag){
    digitalWrite(RELAY_PIN,LOW);   // 通電開始
  } else {
    digitalWrite(RELAY_PIN,HIGH);  // 通電終了
  }
}

/*
   shutdownコマンドの処理
     Piと接続してるshutdownピンをSHUTDOWN_PIN_DURATION(秒)間HIGHにする
     shutdownピンをLOWにする
     SHUTDOWN_WAIT_DURATION(秒)待つ
 */
void forcePiShutdown(){
#ifdef LCD
  lcd.clear();
  lcd.print(F("Shutdown signal"));
  lcd.setCursor(0, 1);
#endif /* LCD */
  //printMessage("Start shutdown procedure of raspberry Pi.\n",CONSOLE_SERIAL);
  //printMessage("Sending shutdown signal to Pi.",CONSOLE_SERIAL);
  CONSOLE.println("Start shutdown procedure of raspberry Pi.");
  CONSOLE.print("Sending shutdown signal to Pi.");
  digitalWrite(SHUTDOWN_PIN,HIGH);            // Raspberry Piにshutdown指示するピンをHIGH
  int i;
  for (i=0;i<SHUTDOWN_PIN_DURATION;i++) {     // SHUTDOWN_PIN_DURATION(秒)だけ待機
#ifdef LCD
    lcd.print(F("."));
#endif /* LCD */
    //printMessage(".",CONSOLE_SERIAL);
    CONSOLE.print(".");
    delay(1000);
  }
#ifdef LCD
  lcd.print(F("done"));
#endif /* LCD */
  //printMessage("done\n",CONSOLE_SERIAL);
  CONSOLE.println("done.");
  digitalWrite(SHUTDOWN_PIN,LOW);             // Raspberry Piにshutdown指示するピンをLOW (Raspberry Piは信号に気づいてshutdownしているはず)
#ifdef LCD
  lcd.clear();
  lcd.print(F("Waiting for Pi"));
  lcd.setCursor(0, 1);
#endif /* LCD */
  //printMessage("Waiting for Pi.",CONSOLE_SERIAL);
  CONSOLE.print("Waiting for Pi.");
  for (i=0;i<SHUTDOWN_WAIT_DURATION;i++) {    // Raspberry Piのshutdown処理が終わるのを待つ (信号はないので，とにかく一定時間待つ)
#ifdef LCD
    lcd.print(F("."));
#endif /* LCD */
    //printMessage(".",CONSOLE_SERIAL);
    CONSOLE.print(".");
    delay(1000);
  }
#ifdef LCD
  lcd.print(F("done"));
#endif /* LCD */
  //printMessage("done\n",CONSOLE_SERIAL);
  CONSOLE.println("done");
}

/*
   reboot
     shutdownして電源をOFF，一定時間待って，電源ON
 */
void reboot() {
  int i;
  forcePiShutdown();
#ifdef LCD
  lcd.clear();
  lcd.print(F("Power OFF"));
  lcd.setCursor(0, 1);
#endif /* LCD */
  //printMessage("Power OFF",CONSOLE_SERIAL);
  CONSOLE.print("Power OFF");
  relayControl(false);              // 電源OFF
  for (i=0;i<POWER_ON_WAIT;i++) {   // 一定時間待機
    //printMessage(".",CONSOLE_SERIAL);
    CONSOLE.print(".");
#ifdef LCD
    lcd.print(F("."));
#endif /* LCD */
    delay(1000);
  }
  //printMessage("done\n",CONSOLE_SERIAL);
  CONSOLE.println("done");
#ifdef LCD
  lcd.print(F("done"));
#endif /* LCD */
  //printMessage("Power ON\n",CONSOLE_SERIAL);
  CONSOLE.println("Power ON");
#ifdef LCD
  lcd.clear();
  lcd.print(F("Power ON"));
#endif /* LCD */
  relayControl(true);               // 電源ON
}

/*
 HELP             (コマンドの説明の出力)
  S:shutdown         (shutdownピンを1秒HIGH)
  U:Power ON         (リレー用端子をLOW)
  D:Power OFF        (リレー用端子をHIGH)
  I:Info            (各種の状態を返す)
  H|? : HELP             (コマンドの説明の出力)
  Q : Quit  管理者モードを抜ける
*/

#define COMMAND_HELP_MESSAGE "S : Shutdown\nU : power Up\nD : power Down\nI : Info\nH|? : Help\nQ : Quit\n"
void printCommandHelp() {
  //printMessage(COMMAND_HELP_MESSAGE,CONSOLE_SERIAL );
  CONSOLE.println("S : Shutdown");
  CONSOLE.println("U : power Up");
  CONSOLE.println("D : power Down");
  CONSOLE.println("I : Info");
  CONSOLE.println("H|? : Help");
  CONSOLE.println("Q : Quit");
}

/*
   ログインコマンドエラー通知
 */
#define LOGIN_COMMAND_ERROR_MESSAGE "L : Login to control command line mode\n"
void printControlCommandError(){
  //printMessage(LOGIN_COMMAND_ERROR_MESSAGE,CONSOLE_SERIAL);
  CONSOLE.println("L : Login to control command line mode");
}

/*
   コマンドにない文字を入力した場合のエラー通知
 */
void printInputCommand(char input){
  //char buff[64];
  //sprintf(buff,"Error : you input unknown character '%c'.\n",input);
  //printMessage(buff,CONSOLE_SERIAL);
  CONSOLE.print("Error : you input unknown character '");
  CONSOLE.print(input);
  CONSOLE.println("'.");
}

/*
   エラー処理エントリ関数
      入力した文字が有効な文字か否かは，管理者モードにログイン前かログイン後で変化するため
*/
void printCommandErrorMessage(int state, char input){
  printInputCommand(input);
  switch(state) {
    case 0 : // 管理者モードでの不正文字入力
      printCommandHelp();
      break;
    case 1 : // 通常時にログイン以外の文字を入れた
      printControlCommandError();
      break;
  }
}

/*
 "通常 (STATE_NORMAL) "状態から他の状態に遷移する際の判定と遷移の際の処理
   【処理がある遷移】
    (1) keep alive 警告がある場合は，rebootしてkeep aliveを初期化して元に戻る
    (2) 高温信号があったら，shutdown+電源OFFし，タイマを仕掛けて電源OFF状態に遷移
    (3) 体感温度が一定以上の場合は，shutdown+電源OFFしてタイマを仕掛けて電源OFF状態に遷移
    (4) 電源ボタンが一定時間以上押されていたら，shutdown+電源OFFし，強制電源OFF状態に遷移
   【処理がない遷移】
    (5) 管理者状態への遷移要求があったら，通情管理者状態(STATE_NORMAL_CONTROL)に遷移
    (6) 想定外の文字列入力には，管理者モードへの入力説明を表示してもとに戻る
 */
int transition_normal(){
  if (event.powerPinCounter > POWER_PIN_THRESHOLD) { // 電源ボタンを一定時間押した場合 (4)
#ifdef LCD_COLOR
    lcd_causion();
#endif /* LCD_COLOR */
    forcePiShutdown();
    //printMessage("Power OFF",CONSOLE_SERIAL);
    CONSOLE.print("Power OFF");
#ifdef LCD
    lcd.clear();
    lcd.print(F("Power OFF"));
#endif /* LCD */
    relayControl(false);              // 電源OFF
    event.powerPinCounter=0;
    return STATE_FOFF;
  }
  if (event.keepAlive) {       // Raspberry Piがkeep alive信号を一定時間以上出さなかった． (1)
    // リブートして，通常状態に戻る
#ifdef LCD_COLOR
    lcd_allert();
#endif /* LCD_COLOR */
    reboot();
    keepAlive=now();
    infoTimer=now();
#ifdef LCD_COLOR
    lcd_normal();
#endif /* LCD_COLOR */
    return STATE_NORMAL;
  }
  if ((event.highTemperature)||(event.envTemperature==ENV_TEMPERATURE_HIGH)) {  // 環境温度か，PiのCPU温度が高い(2)か(3)
    // shutdownして，一定時間放置するためのタイマを走らせる．
#ifdef LCD_COLOR
    lcd_allert();
#endif /* LCD_COLOR */
    forcePiShutdown();
    //printMessage("Power OFF",CONSOLE_SERIAL);
    CONSOLE.print("Power OFF");
#ifdef LCD
    lcd.clear();/* noro */
    lcd.print(F("Power OFF"));
    lcd.setCursor(0, 1);
#endif /* LCD */
    relayControl(false);              // 電源OFF
    int i;
    for (i=0;i<POWER_ON_WAIT;i++) {   // 一定時間待機
      //printMessage(".",CONSOLE_SERIAL);
      CONSOLE.print(".");
#ifdef LCD
      lcd.print(F("."));
#endif /* LCD */
      delay(1000);
    }
    //printMessage("done\n",CONSOLE_SERIAL);
    CONSOLE.println("done");
#ifdef LCD
    lcd.print(F("done"));
#endif /* LCD */
    relayControl(false);
    startTimer();
    return STATE_OFF;
  }
  if (event.commandInput==COMMAND_CONTROL_MODE) {  // 管理者がログインした(5)
    // 管理者との対話処理(状態)に遷移
    //printMessage("Entering command line mode.\n",CONSOLE_SERIAL);
    CONSOLE.println("Entering command line mode.");
    printCommandHelp();
    return STATE_NORMAL_CONTROL;
  } else if (event.commandInput!=COMMAND_NONE) {   // コマンドとして意味がない文字が入力された (6)
    printCommandErrorMessage(1, event.commandInputChar); // エラーの表示
  }
  if ((infoTimer+INFO_INTERVAL) < now()){
    infoTimer=now();
    printInfo(STATE_NORMAL);
  }
#ifdef LCD_COLOR
  lcd_normal();
#endif /* LCD_COLOR */
  return STATE_NORMAL; //特に何もなければ，元の状態に戻る
}
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
void loop() {
  checkEvent();  // イベントの有無の確認処理
#if defined(DEBUG) && defined(DEBUG_EVENT)
  dumpEvent();
#endif /* DEBUG */
  switch (currentState) { // 状態遷移処理
    case STATE_NORMAL:
      currentState=transition_normal();
      break;
    case STATE_OFF:
      currentState=transition_off();
      break;
    case STATE_FOFF:
      currentState=transition_foff();
      break;
    case STATE_NORMAL_CONTROL:
      currentState=transition_control_normal();
      break;
    case STATE_FOFF_CONTROL:
      currentState=transition_control_foff();
      break;
    case STATE_OFF_CONTROL:
      currentState=transition_control_off();
  }
  delay(LOOP_WAIT_TIME); // 次のイベントチェックまでの待ち時間
#ifdef SOFT_WDT
  wdt_reset();
#endif /* SOFT_WDT */
}

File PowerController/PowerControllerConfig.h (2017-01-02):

/*
 * 機種の定義
 */
//#define UNO
#define MEGA
//#define YUN

/*
 * 利用する機能の定義
 */
//#define DEBUG
//#define DEBUG_EVENT
//#define DEBUG_POWER_PIN
#define DHT_WAIT
#define LCD
#define LCD_COLOR
#define SOFT_WDT

//#define ESP8266_HACK  // ESP8266のシリアルのごみ問題対応

//#define SOFT_SERIAL // Uno系の端末で標準シリアル以外を利用する場合に必要
//#define BRIDGE // YunのConsole機能用
#define SERIAL
//#define SERIAL1 // 注 : MegaのSerial1は割り込み処理用の端子とかちあう可能性あり
//#define SERIAL2
//#define SERIAL3

// 割り込みが使えない機種(例 : YUN)の場合は以下を有効にする
//#define NO_INTERRUPT

/*

ピン配列の定義
 
 用途                           Raspberry Pi     UNO
 【割り込み信号 Pi -> Arduino】
 keep alive                         17            2 (黄)
 高温信号                           27            3 (緑)
 【Arduino -> Pi】
 shutdown                           22            7 (青)
 【温度センサ】
  DHTデータピン                                   4
 【電源制御】
  リレーのコントール端子                          5
  パワーボタン                                    6

*/
#ifdef UNO
#define KEEP_ALIVE_PIN  2  // 黄  2
#define HIGH_TEMP_PIN   3  // 緑  3
#define SHUTDOWN_PIN    7  // 青
#define DHT_PIN         4
#define RELAY_PIN       5
#define POWER_PIN       6
#endif /* UNO */

#ifdef MEGA
// MEGAで割り込み可能なピン番号 : 2,3,18,19,20,21
//
// MEGAのシリアルピン番号
//          SERIAL1         SERIAL2       SERIAL3
//   RX       19               17            15
//   TX       18               16            14
//#define KEEP_ALIVE_PIN  2  // 黄  2
//#define HIGH_TEMP_PIN   3  // 緑  3
#define KEEP_ALIVE_PIN  18  // 黄  18
#define HIGH_TEMP_PIN   19  // 緑  19
#define SHUTDOWN_PIN    7  // 青
#define DHT_PIN         4
#define RELAY_PIN       5
#define POWER_PIN       6
#endif /* MEGA */

#ifdef YUN
// 2と3がI2Cとかち合うことと，pin7がLinux用チップとかちあうため，UNOとは違うピン配置にする
#define KEEP_ALIVE_PIN  10  // 黄  10
#define HIGH_TEMP_PIN   11  // 緑  11
#define SHUTDOWN_PIN    12  // 青
#define DHT_PIN         4
#define RELAY_PIN       5
#define POWER_PIN       6
#endif /* YUN */


#ifdef SOFT_SERIAL
#define SOFT_SERIAL_RX  9
#define SOFT_SERIAL_TX  8
#endif /* SOFT_SERIAL */


/*
 * 各種定数の定義
 */
#define LOOP_WAIT_TIME    500             // 0.5s

//イベント監視関連の定数
#define KEEP_ALIVE_THRESHOLD 60            // キープアライブがタイムアウトする時間間隔 60秒
#define HI_LOW_THRESHOLD     40            // 環境の温度のしきい値(下)
#define HI_HIGH_THRESHOLD    50            // 環境の温度のしきい値(上)
//#define HI_LOW_THRESHOLD     20            // 環境の体感温度のしきい値(下)
//#define HI_HIGH_THRESHOLD    27            // 環境の体感温度のしきい値(上)
#ifdef DEBUG
#define HIGH_TEMPERATURE_WAIT_DURATION 30 // 高温時の待ち時間 (30秒)
#else /* DEBUG */
#define HIGH_TEMPERATURE_WAIT_DURATION 300 // 高温時の待ち時間 5分 (300秒)
#endif /* DEBUG */
#define COMMAND_LINE_WAIT_DURATION 300     // 管理モード自動ログオフの待ち時間 5分 (300秒)

// 管理者コマンドラインで，温・湿度を測定する際のリトライ回数最大値
//#define SENSOR_MAX_RETRY 5

// Raspberry Piをshutdownする際の待ち時間
#define SHUTDOWN_PIN_DURATION    2       // shutdown信号のピンをHIGHに固定する時間(秒)
#define SHUTDOWN_WAIT_DURATION  10       // shutdown処理が走るのを待つ時間(秒)

// Raspberry Piをrebootする時の電源ON/OFFの操作の間の待ち時間
#define POWER_ON_WAIT 5                  // 確実に電源を切断するためOFF->5秒待ち->ONとする

// コンソール画面で一定時間間隔で運転状況を表示するための時間間隔
#define INFO_INTERVAL 10                // 10s

// パワースイッチを押して有効にするためのしきい値(時間)
#define POWER_PIN_THRESHOLD    2        // イベントチェック3回

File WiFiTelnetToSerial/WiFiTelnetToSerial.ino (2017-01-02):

#define DEBUG
#define CONSOLE_MESSAGE
#define ESP
//#define SOFT_SERIAL

#define TIMER_THRESHOLD 60
#define MAX_PASS_RETRY 3

#define MAX_FILENAME_BUFF_SIZE 64
#define MAX_WIFI_SSID_SIZE 32
#define MAX_WIFI_PASS_SIZE MAX_WIFI_SSID_SIZE
#define MAX_USER_PASS_SIZE MAX_WIFI_SSID_SIZE

//how many clients should be able to telnet to this ESP8266
//#define MAX_SRV_CLIENTS 1

#define SD_CHIP_SELECT 5
#define LOGIN_PASSWD_FILE "pass.txt"
#define WIFI_SSID_FILE "ssid.txt"
#define WIFI_PASS_FILE "wifipass.txt"

#define SOFT_SERIAL_RX_PIN 16
#define SOFT_SERIAL_TX_PIN 4

/*
  状態遷移
    初期状態    STATE_START          0
    ログイン    STATE_LOGIN          1
    コマンド    STATE_COMMAND        2
    中継        STATE_RELAY          3
 */
#define STATE_NONE    0
#define STATE_START   1
#define STATE_LOGIN   2
#define STATE_COMMAND 3
#define STATE_RELAY   4
/*
   管理者用コマンド
    COMMAND_OPEN           'O'     : シリアルをオープン
    COMMAND_HELP           'H'|'?' : HELP             (コマンドの説明の出力)
    COMMAND_EXIT           'Q'     : Quit  管理者モードを抜ける
    COMMAND_REBOOT         'R'     : リブート
    COMMAND_ESCAPE         '^A'    : シリアルをクローズ
    COMMAND_UNKNOWN        コマンドに対応しない文字の入力時
    COMMAND_NONE           入力なし
*/
#define COMMAND_NONE          0
#define COMMAND_UNKNOWN       1
#define COMMAND_OPEN          2
#define COMMAND_HELP          3
#define COMMAND_EXIT          4
#define COMMAND_ESCAPE        5
#define COMMAND_REBOOT        6

#include <SPI.h>
#include <SD.h>
#include <ESP8266WiFi.h>

#ifdef SOFT_SERIAL
#include <EspSoftwareSerial.h>
EspSoftwareSerial swSer(SOFT_SERIAL_RX_PIN,SOFT_SERIAL_TX_PIN, false, 256);  // Rx ,Tx, inverse_logic, buffSize
#endif /* SOFT_SERIAL */

char wifi_ssid[MAX_WIFI_SSID_SIZE];
char wifi_pass[MAX_WIFI_PASS_SIZE];
char passwd[MAX_USER_PASS_SIZE];
int currentState=COMMAND_NONE;

WiFiServer server(23);
//WiFiClient serverClients[MAX_SRV_CLIENTS];
WiFiClient serverClient;

String readFileEntry(String filename){
  char buff[MAX_FILENAME_BUFF_SIZE];
  filename.toCharArray(buff, MAX_FILENAME_BUFF_SIZE);
  File tmpFile=SD.open(buff);
  if (tmpFile) {
#ifdef DEBUG
    Serial.print("open file = ");
    Serial.println(filename);
#endif /* DEBUG */
    // read from the file until there's nothing else in it:
    while (tmpFile.available()) {
      String line = tmpFile.readStringUntil('\n');
      if ('#'!=line.charAt(0)) {
        tmpFile.close();
#ifdef DEBUG
        Serial.println(line);
#endif
        return line;
      }
    }
  } else {
#ifdef CONSOLE_MESSAGE
    // if the file didn't open, print an error:
    Serial.println("error opening file");
#endif
  }
  tmpFile.close();
  return "";
}

void initSdCard(){
#ifdef CONSOLE_MESSAGE
  Serial.print("Initializing SD card...");
#endif
  if (!SD.begin(SD_CHIP_SELECT)) {
#ifdef CONSOLE_MESSAGE
    Serial.println("initialization failed!");
#endif
    return;
  }
#ifdef CONSOLE_MESSAGE
  Serial.println("initialization done.");
#endif
}

void readConfigFiles(){
  readFileEntry(LOGIN_PASSWD_FILE).toCharArray(passwd,MAX_USER_PASS_SIZE);
  for (int i=0 ; i< MAX_USER_PASS_SIZE;i++){
    if ((passwd[i]<32) || (passwd[i]>126)) {
      passwd[i]=0;
    }
  }
  readFileEntry(WIFI_SSID_FILE).toCharArray(wifi_ssid,MAX_WIFI_SSID_SIZE);
  for (int i=0 ; i< MAX_WIFI_SSID_SIZE;i++){
    if ((wifi_ssid[i]<32) || (wifi_ssid[i]>126)) {
      wifi_ssid[i]=0;
    }
  }
  readFileEntry(WIFI_PASS_FILE).toCharArray(wifi_pass,MAX_WIFI_PASS_SIZE);
  for (int i=0 ; i< MAX_WIFI_PASS_SIZE;i++){
    if ((wifi_pass[i]<32) || (wifi_pass[i]>126)) {
      wifi_pass[i]=0;
    }
  }
}

void printCommandHelp() {
  serverClient.println("Command mode");
  serverClient.println("\tO : open serial port");
  serverClient.println("\tH|? : Help");
  serverClient.println("\tQ : Quit");
  serverClient.println("\tR : reboot");
  serverClient.println("Console mode");
  serverClient.println("\t^A : close console port");
//  printMessage(COMMAND_HELP_MESSAGE,CONSOLE_SERIAL );
}

/*
  管理者インターフェースから入力されたコマンド(文字)の解析処理
  https://ja.wikipedia.org/wiki/ASCII#ASCII.E5.88.B6.E5.BE.A1.E6.96.87.E5.AD.97

   ASCIIコードの制御文字の代表例
   16進数         CS              意味
     00           ^@            ヌル文字
     01           ^A            ヘッディング開始
     03           ^C            テキスト終了
     04           ^D            伝送終了
     18           ^X            取り消し
     1A           ^Z            置換
     1B           ^[            エスケープ
 */
int commandLex(char input){
  switch (input) {
    case 'o': // シリアルポートで管理者がコマンドモードを利用する場合の合図
    case 'O':
      return COMMAND_OPEN;
    case 'H': // ヘルプ
    case 'h':
    case '?':
      return COMMAND_HELP;
    case 'Q': // 管理者コマンドモードからのログアウト
    case 'q':
      return COMMAND_EXIT;
    case 0x01 :
      return COMMAND_ESCAPE;
    case 'R' : // リブートコマンド
    case 'r' :
      return COMMAND_REBOOT;
  }
  return COMMAND_UNKNOWN; // 未定義の文字が入力された
}

void printLoginMessage(){
  serverClient.print("Please enter passwd to login : ");
}

boolean checkPasswd(char *loginPasswd){
/*
#ifdef DEBUG
  Serial.println("checkPasswd ");
  Serial.print("loginPasswd = ");
  Serial.println(loginPasswd);
  Serial.print("passwd = ");
  Serial.println(passwd);
  int test=strncmp(passwd,loginPasswd,MAX_PASS_LENGTH-1);
  Serial.print("strncmp(passwd,loginPasswd,MAX_PASS_LENGTH-1) = ");
  Serial.println(test);
#endif
*/
  if (0==strncmp(passwd,loginPasswd,MAX_USER_PASS_SIZE-1)) {
    return true;
  }
  return false;
}

boolean loginTest(){
  startCommandLineTimer();
#ifdef DEBUG
  Serial.println("");
  Serial.println("start loginTest()");
#endif /* DEBUG */
  //String loginPasswd = Serial.readStringUntil('\n');
  char loginPasswd[MAX_USER_PASS_SIZE];
#ifdef DEBUG
  //Serial.print("serverClient.available() = ");
  //Serial.println(serverClient.available());
#endif /* DEBUG */

  for (int i=0; i<MAX_PASS_RETRY;i++) {
    memset(loginPasswd,0,MAX_USER_PASS_SIZE);
    int j=0;
#ifdef DEBUG
  //Serial.print("serverClient.available() = ");
  //Serial.println(serverClient.available());
#endif /* DEBUG */
    for (;;){
      if (checkCommandLineTimer()){
        return false;
      }
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

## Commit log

2016-08-12 READMEの図のテストと，.gitignoreにvim関係の定義を追加
2016-08-12 readme.mdの図のテスト用画像の追加
2016-08-12 図のディレクトリの指定方法の変更と，システム構成の図を全て追加
2016-08-12 図のディレクトリ指定を変更
2016-08-12 システム構成図を全て追加
2016-08-12 図の追加
2016-08-12 拡張子を忘れていたので追加
2016-08-12 電源制御回路の画像を追加
2016-08-12 図のファイル名を変更
2016-08-12 図のファイル名の表記方法を変更
2016-08-13 回路図関係を全て追加
2016-08-13 一通り，全てのドキュメントとソースコード，図面を追加．
    [Arduino電源制御回路-UNOシールド.fzz, Arduino電源制御回路-yunシールド.fzz, Arduino電源制御回路-ブレッドボード.fzz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]
2016-08-13 章や節に番号を追加
2017-01-02 megaとunoなど，機種別に分けたため，削除
    [WROOM2-Arduino相互接続シールド-Arduino用.fzz]
2017-01-02 外側だけしかなかったドキュメントの中身を記述した．
2017-01-02 megaとyun用の定義の追加と，一部のtypoの修正，コメントの追加
2017-01-02 mega用にハードウェアシリアルの追加，yun用に端子の変化の検出に割り込みを使わない方法の追加．ワッチドッグタイマの追加．
2017-01-02 通信ポートがソフトシリアルかハードシリアルかの処理の違いをifdefで実現
2017-01-02 Arduino用のシールドにmega用やyun用を追加，さらに，遠隔ログインにESP8266-WROOM2(スイッチサイエンスESPr one)を用いる場合のシールドも追加．
    [Arduino電源制御回路-yunシールド.fzz, Pi-Arduino相互接続シールド-Mega用シンプル.fzz, Pi-Arduino相互接続シールド-Pi用.fzz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]
